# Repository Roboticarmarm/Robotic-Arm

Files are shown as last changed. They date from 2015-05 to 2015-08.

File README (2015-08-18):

Robotic Arm Control Codebase
------------------------OVERVIEW--------------------------
1. arm.sh-Basic control sample code for RK3188 (1 servo)
2. arm.ino-Basic control sample code for Arduino Mega2560
3. serial.ino-Serial base sample code for Arduino Mega2560
4. mainarm.sh-Beta version for RK3188 (hand)
5. mainarm.ino-Beta version for Arduino Mega2560
6. testarm.sh-Testing for the angel
------------------------GUIDELINE-------------------------
For everyone in this project, doc format is here:
{
	For someone in this project - title
	TODO: what is your current task
	ISSIUE: issiues need to be discussed
}

-------------------------TASK LIST------------------------
5/15
For mopplayer : Startup
Basic control for RK3188 and Mega2560.
Testing done.
----

5/22
For mopplayer : Rebuild sirius system for RK3188
ISSUE: 
For testing voice, it spent about 6X secs on
recognition.
Using GCC 4.8.2 is not recommended by office,
they say it will crash.
Retry to build system by using GCC 4.9.3.
----

5/29
For mopplayer : System has been finished
GCC 4.9.3 will cause some bug on program, drop it
Using GCC 4.8.2 to rebuild ASR to minimize space.
11G -> 2.5G for space requirement.
Testing done.
----

5/30
For mopplayer : Review control method
ISSIUE:
if use GPIOs to control the servos, we will need
2x17 GPIOs to encode only 4 angels of the servos
I make it more flexible...
----

5/31
For mopplayer : Change GPIOs to Serial
I coded the serial of base, it use ttyUSB to
emulate serial. I also tried UART, but there are
some bugs on sync, so drop it.
Push serial code, it will be combined.
----

6/4
For mopplayer : Release beta version for host
This beta version is only for hand control,
only uses linux host to control,
and doesn't involve voice recognition.
It supported a "hold" operation.
----

6/5
For mopplayer : GCC issiue solved
Now waiting for New configured GCC 4.9.3.
ISSUE:
The robotic arm is overloaded by the torque 
of the base servo, it need time to solve.
----

6/12
For mopplayer: Hardware review
ISSIUE:
The robotic arm is modified to move horizontally,
but the strcture is still weak, we will add screws to fix this.

6/24
For mopplayer: Simplify arm
Basic hold control
Done.

6/29
For mopplayer : car go and grap
version 1.0 release
Done.
 
7/2
For mopplayer : Refine the control
version 1.1 release
Done.

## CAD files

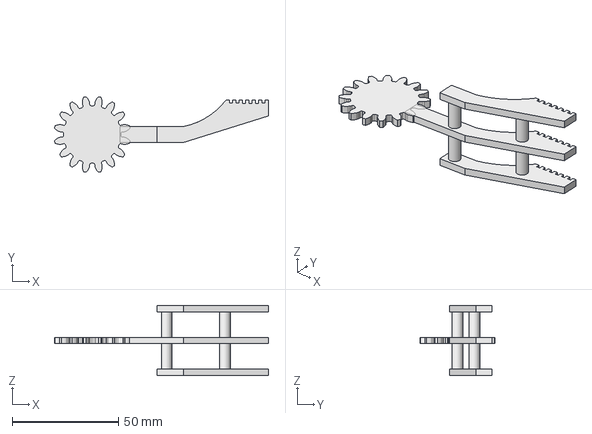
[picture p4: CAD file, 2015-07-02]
FreeCAD/hand.fcstd
100.8 x 35.5 x 33.0 mm

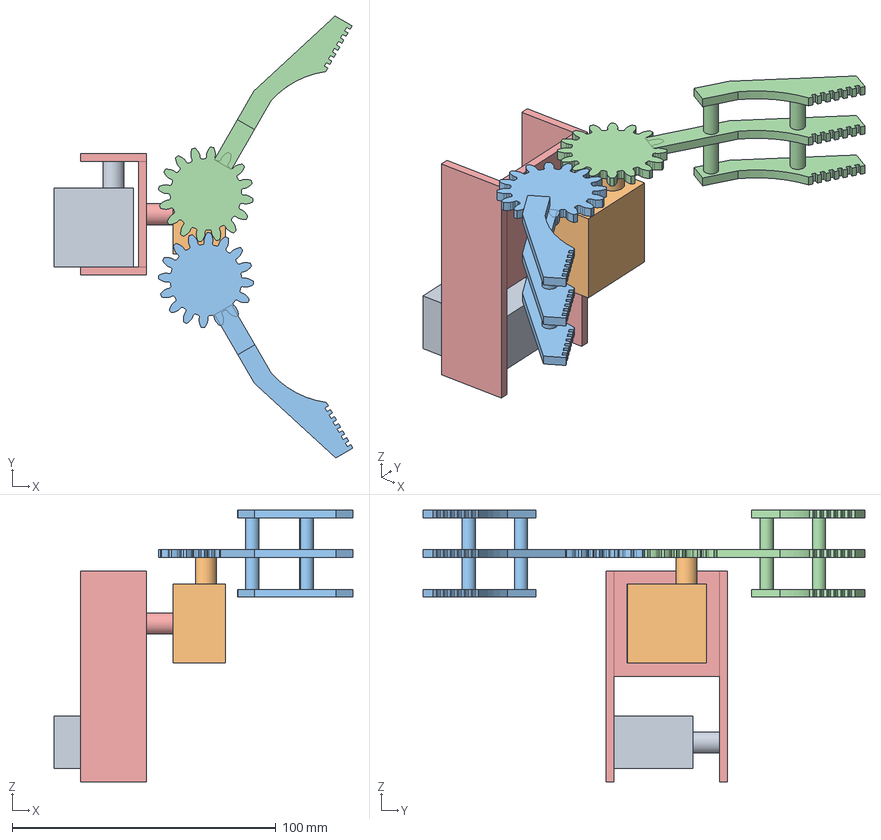
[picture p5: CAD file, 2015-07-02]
FreeCAD/robotic_arm2.fcstd
113.2 x 167.5 x 103.0 mm
right_hand001
left_hand001
arm2

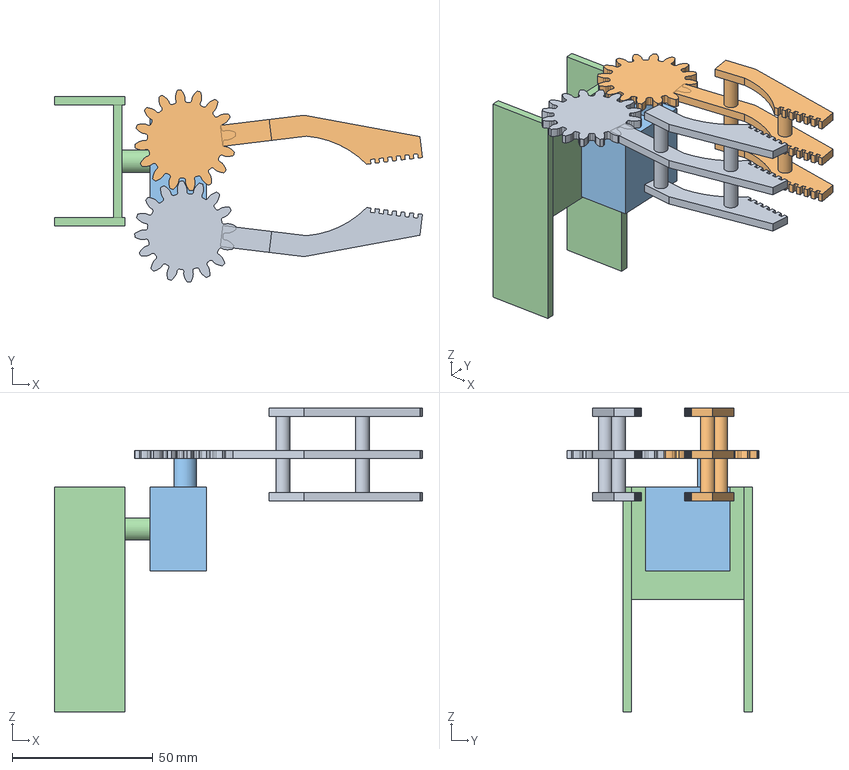
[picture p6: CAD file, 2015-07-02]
FreeCAD/robotic_arm.fcstd
130.9 x 68.4 x 108.0 mm
right_hand001
left_hand001

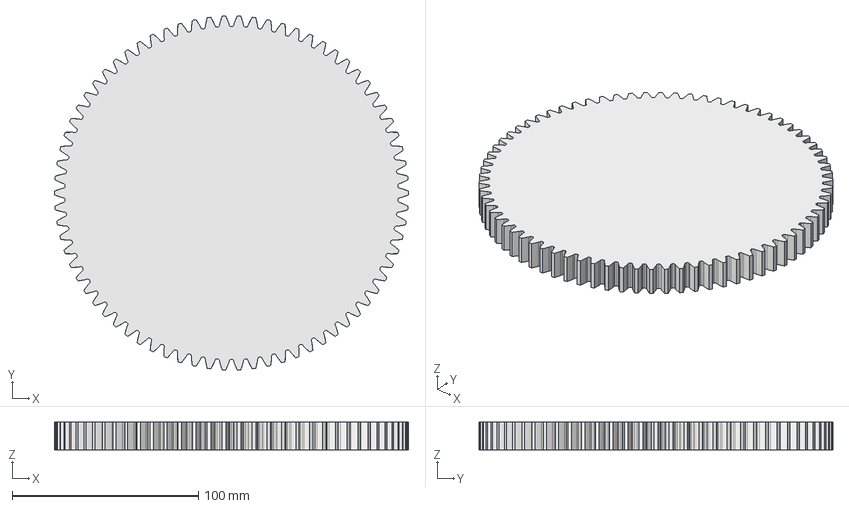
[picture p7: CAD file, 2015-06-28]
FreeCAD/test1.fcstd
190.0 x 189.9 x 15.0 mm

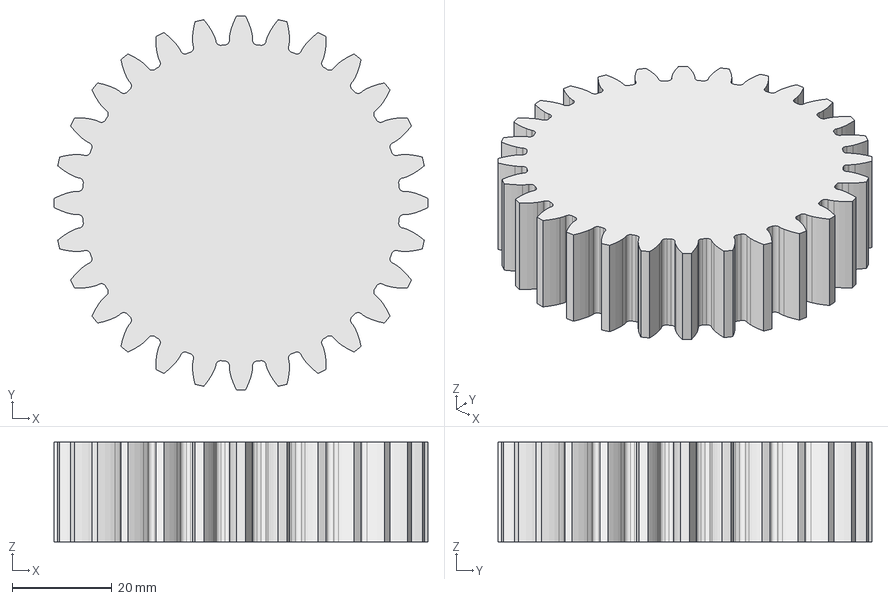
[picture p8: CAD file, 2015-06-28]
FreeCAD/test2.fcstd
75.0 x 75.0 x 20.0 mm

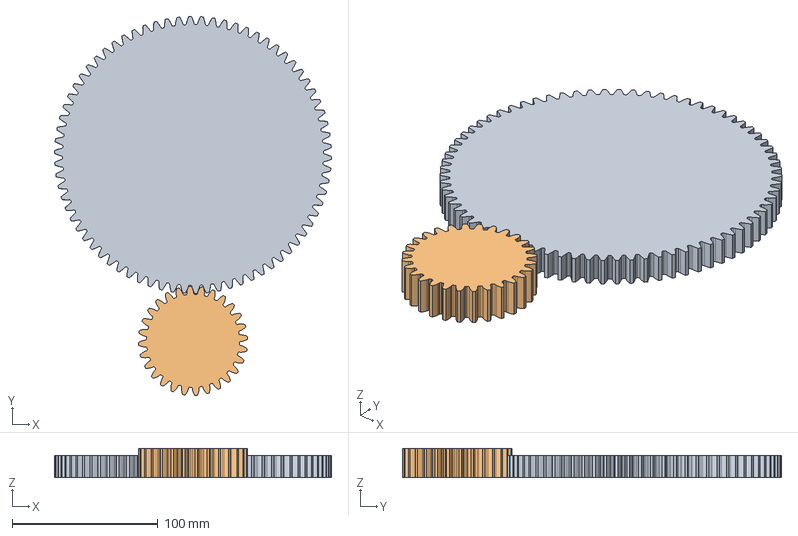
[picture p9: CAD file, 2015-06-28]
FreeCAD/test_2gears.fcstd
190.0 x 260.0 x 20.0 mm

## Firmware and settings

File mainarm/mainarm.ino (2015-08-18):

//Beta version for hand control

#include <Servo.h>
const int DISTANCE=80;
const int NUM=4;
const int sped=75;
int incomingByte=0 ;
int data[NUM]={};
int current[NUM]={};
int count=0;
int index=0;
Servo th1,th2,th3,fo1;
int pos = 0;

void setup() {
  th1.attach(2); 
  th2.attach(5);  
  th3.attach(6);  
  fo1.attach(9);  
  pinMode(7, OUTPUT);
  pinMode(4, OUTPUT);
  pinMode(10, OUTPUT);
  pinMode(11, OUTPUT);
  pinMode(12, OUTPUT);
  pinMode(13, OUTPUT);
  pinMode(3, OUTPUT);
  pinMode(8, INPUT);
  Serial.begin(115200);
}

void loop() {
  long duration, mm;    
  analogWrite(3, sped);	//PWM	
  analogWrite(11, sped);
  
  digitalWrite(7, LOW);
  delayMicroseconds(2);
  digitalWrite(7, HIGH);
  delayMicroseconds(20);
  digitalWrite(7, LOW);
  
  duration = pulseIn(8, HIGH);
  mm = duration*34/200;
  Serial.print(mm);
  Serial.print("mm");
  Serial.println();
  
  if (current[0]==70 && current[1]==80 && current[2]==90 && current[3]==80)
  {
    if(mm<=DISTANCE)
    {
      current[0]=10;
      current[1]=80;
      current[2]=0;
      current[3]=80;
      backward(4,10,13,12);
    }
    else
    {
      forward(4,10,13,12);
    }
  }
  else if (current[0]==10 && current[1]==80 && current[2]==0 && current[3]==80)
  {
    backward(4,10,13,12);
  }
  else
  {
    mstop(4,10,13,12);
  }
  if (Serial.available()) 
  {  
    incomingByte = Serial.read();
    if (incomingByte==10)
    {
           
      for(int i=0;i<NUM;i=i+1)
      {
        current[i]=data[i];
        Serial.print(data[i]);
        Serial.print(",");
      }
      Serial.println("...processing");
          
      for(int i=0;i<NUM;i=i+1)
      {
        data[i]=0;
      }      
      count=-1;
      index=0;              
    }
    else if (incomingByte==44)
    { 
      index=index+1;
    }
    else
    {
      if(count%3==0)
      {
        data[index]=data[index]+(incomingByte-48)*10;
      }
      else
      {
        data[index]=data[index]+(incomingByte-48);
      }
    }
    count=count+1;
  }
  else
  {
    WriteServo(current[0], current[1], current[2]+20, current[3]); //write fetcing data to servo
  }
}

void WriteServo(int a1, int a2, int a3, int b1)
{
    th1.write(a1);
    delay(1);   
    th2.write(a2);
    delay(1);
    th3.write(a3);
    delay(1);
    fo1.write(b1);
    delay(1);  
}

void forward(int in1,int in2,int in3,int in4)
{
    digitalWrite(in1,HIGH);
    digitalWrite(in2,LOW);
    digitalWrite(in3,HIGH);
    digitalWrite(in4,LOW);
}

void backward(int in1,int in2,int in3,int in4)
{
    digitalWrite(in1,LOW);
    digitalWrite(in2,HIGH);
    digitalWrite(in3,LOW);
    digitalWrite(in4,HIGH);
}

void mstop(int in1,int in2,int in3,int in4)
{
    digitalWrite(in1,LOW);
    digitalWrite(in2,LOW);
    digitalWrite(in3,LOW);
    digitalWrite(in4,LOW);
}

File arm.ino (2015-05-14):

#include <Servo.h> 
//For Mega2560 
Servo myservo;  // create servo object to control a servo 
                // twelve servo objects can be created on most boards
void setup() 
{ 
  pinMode(8,INPUT);
  myservo.attach(9);  // attaches the servo on pin 9 to the servo object 
} 
 
void loop() 
{ 
    if (digitalRead(8) == HIGH)
    {    
       myservo.write(120);             
       delay(15);     // waits 15ms for the servo to reach the position 
    }      
    else
    {    
       myservo.write(30);         
       delay(15);    // waits 15ms for the servo to reach the position 
    }       
} 

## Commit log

2015-06-16 get iif feature
    [iif.csv]
2015-06-16 keyword spotting
    [iif.csv]
2015-06-16 change folder
    [iif.csv]
2015-06-24 Simplify arm
2015-06-28 TODO:record template
    [iif.csv, test.csv]
2015-06-28 TODO run.sh classify
    [1.csv, go_1.csv, go_2.csv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]
2015-06-29 TODO: matlab lauch too slow
    [1.csv, test.csv]
2015-06-29 success!! 4 command
    [iif.csv]
2015-07-02 final script
    [hand.fcstd, robotic_arm.fcstd, robotic_arm2.fcstd]
2015-07-02 move file
    move into arduino dir V1.1
